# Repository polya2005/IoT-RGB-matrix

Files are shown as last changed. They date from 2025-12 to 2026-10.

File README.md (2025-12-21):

# IoT-RGB-matrix

## Functionalities

- Sending custom images (and animations) over WiFi to the display.
- Automatically generate a QR code for display (one application is to rickroll people)
- Serving as a "status" display like date/time, weather, etc.

## Project Components

- 40x40 RGB LED matrix, which is broken down into 25 PCBs of 8x8 matrix
- A control board, which is likely a Raspberry Pi Zero W

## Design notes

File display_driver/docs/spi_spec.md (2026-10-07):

# SPI Communication Specification for the FPGA-Based Display Driver

## Basic Configurations

- Most Significant Bit (MSB) first.
- Clock phase = 0 and clock polarity = 0. Data is sampled on the rising edge of SCLK and shifted out on the falling edge.
- The data are processed byte by byte, i.e., the driver considers bits 0-7 as a command and bits 8-15, 16-23, ... as data.

## Conventions Used
- Byte 0 is the command. Data start at byte 1.

## Commands
### SPI_CMD_NOP

#### Command Byte:
`8'h00`

#### Data Bytes:
None

#### Description:
When the driver receives this command, it does nothing just like the name suggests.

### SPI_CMD_SET_PIXEL

#### Command Byte:
`8'h01`

#### Data Bytes:

| Byte number | Description|
| --- | --- |
| 1 | Row number (0-39) |
| 2 | Column number (0-39) |
| 3 | Red pixel value (0-255) |
| 4 | Green pixel value (0-255) |
| 5 | Blue pixel value (0-255) |

#### Description:
This command sets the pixel at the specified row and column, both zero-based, to the given set of RGB values.

### SPI_CMD_CLEAR_SCREEN

#### Command Byte:
`8'h02`

#### Data Bytes:
None

#### Description:
This command clears the frame buffer, filling every byte with a zero. As a result, all LEDs should be turned off.

### SPI_CMD_WRITE_BUFFER

### Command Byte:
`8'h03`

#### Data Bytes:

| Byte number | Description |
| --- | --- |
| $3(40r+c)+1$ | Red pixel value (0-255) at row $r$ and column $c$ |
| $3(40r+c)+2$ | Green pixel value (0-255) at row $r$ and column $c$ |
| $3(40r+c)+3$ | Blue pixel value (0-255) at row $r$ and column $c$ |

#### Description:
This command fills the frame buffer with the specified pixel values. The pixel values are given from the top left to the right and down.

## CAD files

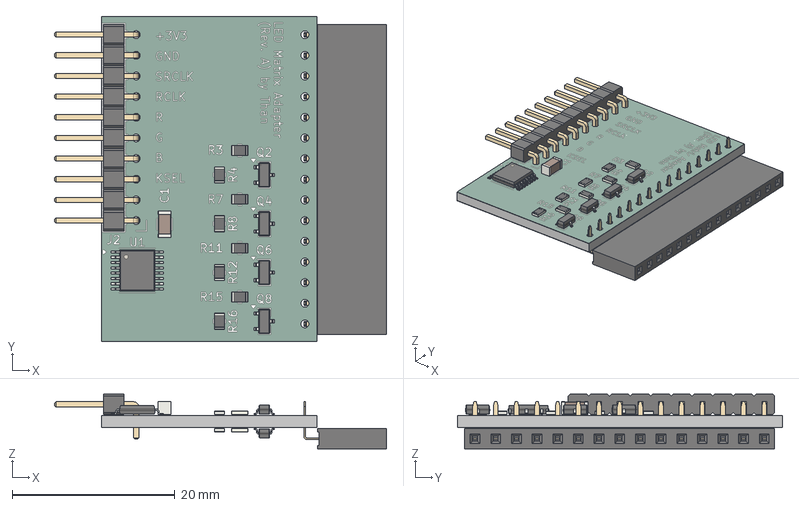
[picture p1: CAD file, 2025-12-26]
pcb/Adapter/Adapter.step
40.8 x 40.0 x 6.76 mm
R_0805_2012Metric x 16
SOT-23 x 8
PinHeader_1x10_P2.54mm_Horizontal
TSSOP-16_4.4x5mm_P0.65mm
C_1206_3216Metric
PinSocket_1x15_P2.54mm_Horizontal
Adapter_silkscreen
Adapter_soldermask
Adapter_PCB

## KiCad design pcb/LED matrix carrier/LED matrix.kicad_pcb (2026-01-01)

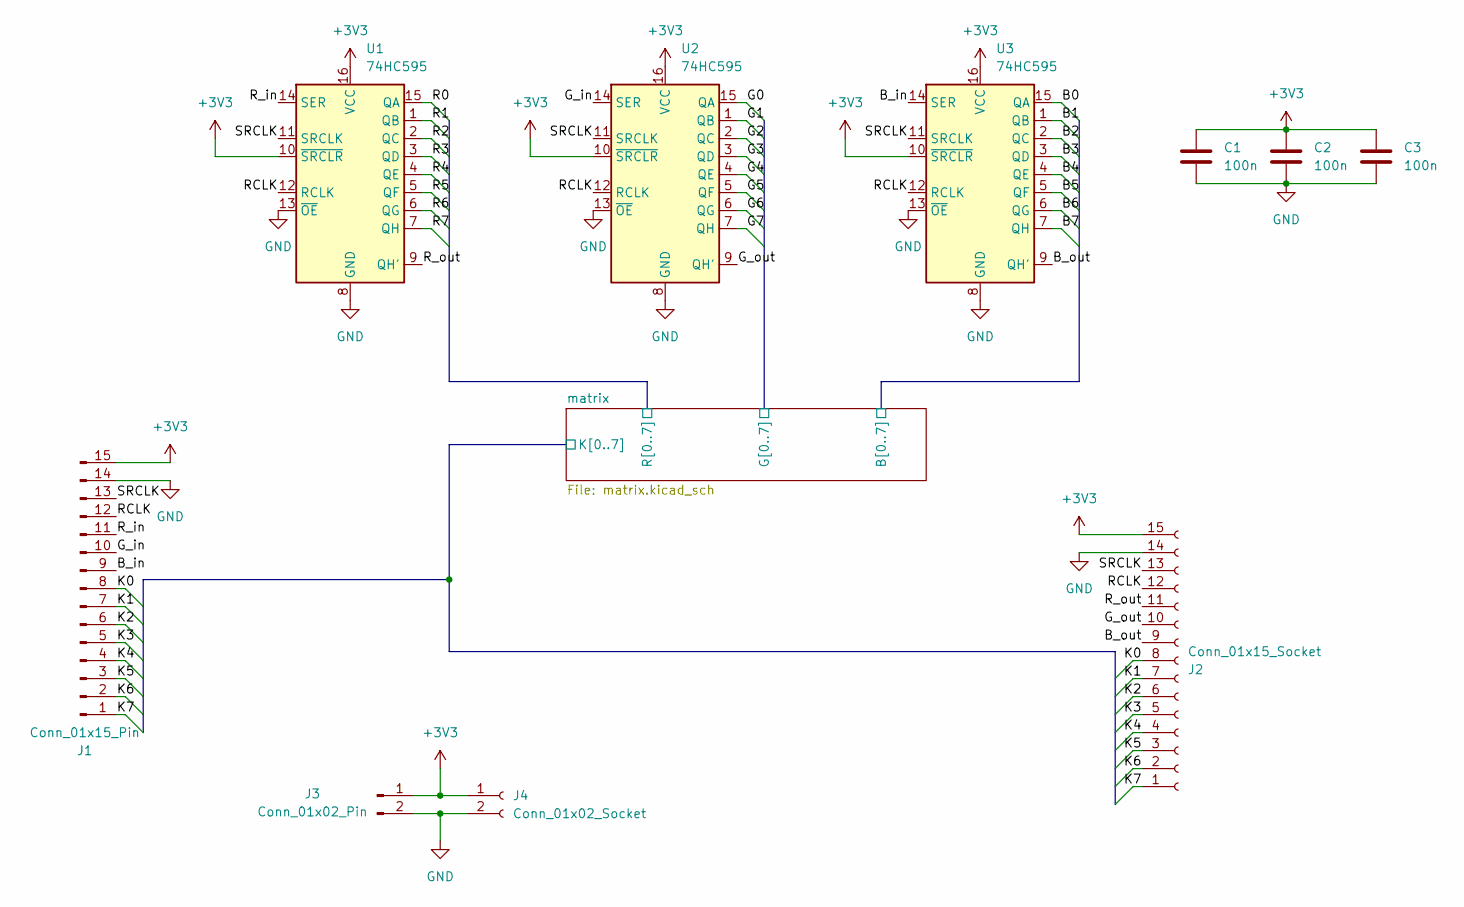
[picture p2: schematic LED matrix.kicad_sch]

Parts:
C1, C2, C3: 100n; C_1206_3216Metric_Pad1.33x1.80mm_HandSolder
J1: Conn_01x15_Pin; PinHeader_1x15_P2.54mm_Horizontal
J2: Conn_01x15_Socket; PinSocket_1x15_P2.54mm_Horizontal
J3: Conn_01x02_Pin; PinHeader_1x02_P2.54mm_Horizontal
J4: Conn_01x02_Socket; PinSocket_1x02_P2.54mm_Horizontal
U1, U2, U3: 74HC595; TSSOP-16_4.4x5mm_P0.65mm

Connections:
+3V3: C1.1, C2.1, C3.1, J1.15, J2.15, J3.1, J4.1, U1.10 (~SRCLR), U1.16 (VCC), U2.10 (~SRCLR), U2.16 (VCC), U3.10 (~SRCLR), U3.16 (VCC)
/B_in: J1.9, U3.14 (SER)
/B_out: J2.9, U3.9 (QH')
/G_in: J1.10, U2.14 (SER)
/G_out: J2.10, U2.9 (QH')
/RCLK: J1.12, J2.12, U1.12 (RCLK), U2.12 (RCLK), U3.12 (RCLK)
/R_in: J1.11, U1.14 (SER)
/R_out: J2.11, U1.9 (QH')
/SRCLK: J1.13, J2.13, U1.11 (SRCLK), U2.11 (SRCLK), U3.11 (SRCLK)
/matrix/B0: U3.15 (QA); also elsewhere on the board
/matrix/B1: U3.1 (QB); also elsewhere on the board
/matrix/B2: U3.2 (QC); also elsewhere on the board
/matrix/B3: U3.3 (QD); also elsewhere on the board
/matrix/B4: U3.4 (QE); also elsewhere on the board
/matrix/B5: U3.5 (QF); also elsewhere on the board
/matrix/B6: U3.6 (QG); also elsewhere on the board
/matrix/B7: U3.7 (QH); also elsewhere on the board
/matrix/G0: U2.15 (QA); also elsewhere on the board
/matrix/G1: U2.1 (QB); also elsewhere on the board
/matrix/G2: U2.2 (QC); also elsewhere on the board
/matrix/G3: U2.3 (QD); also elsewhere on the board
/matrix/G4: U2.4 (QE); also elsewhere on the board
/matrix/G5: U2.5 (QF); also elsewhere on the board
/matrix/G6: U2.6 (QG); also elsewhere on the board
/matrix/G7: U2.7 (QH); also elsewhere on the board
/matrix/K0: J1.8, J2.8; also elsewhere on the board
/matrix/K1: J1.7, J2.7; also elsewhere on the board
/matrix/K2: J1.6, J2.6; also elsewhere on the board
/matrix/K3: J1.5, J2.5; also elsewhere on the board
/matrix/K4: J1.4, J2.4; also elsewhere on the board
/matrix/K5: J1.3, J2.3; also elsewhere on the board
/matrix/K6: J1.2, J2.2; also elsewhere on the board
/matrix/K7: J1.1, J2.1; also elsewhere on the board
/matrix/R0: U1.15 (QA); also elsewhere on the board
/matrix/R1: U1.1 (QB); also elsewhere on the board
/matrix/R2: U1.2 (QC); also elsewhere on the board
/matrix/R3: U1.3 (QD); also elsewhere on the board
/matrix/R4: U1.4 (QE); also elsewhere on the board
/matrix/R5: U1.5 (QF); also elsewhere on the board
/matrix/R6: U1.6 (QG); also elsewhere on the board
/matrix/R7: U1.7 (QH); also elsewhere on the board
GND: C1.2, C2.2, C3.2, J1.14, J2.14, J3.2, J4.2, U1.8 (GND), U1.13 (~OE), U2.8 (GND), U2.13 (~OE), U3.8 (GND), U3.13 (~OE)

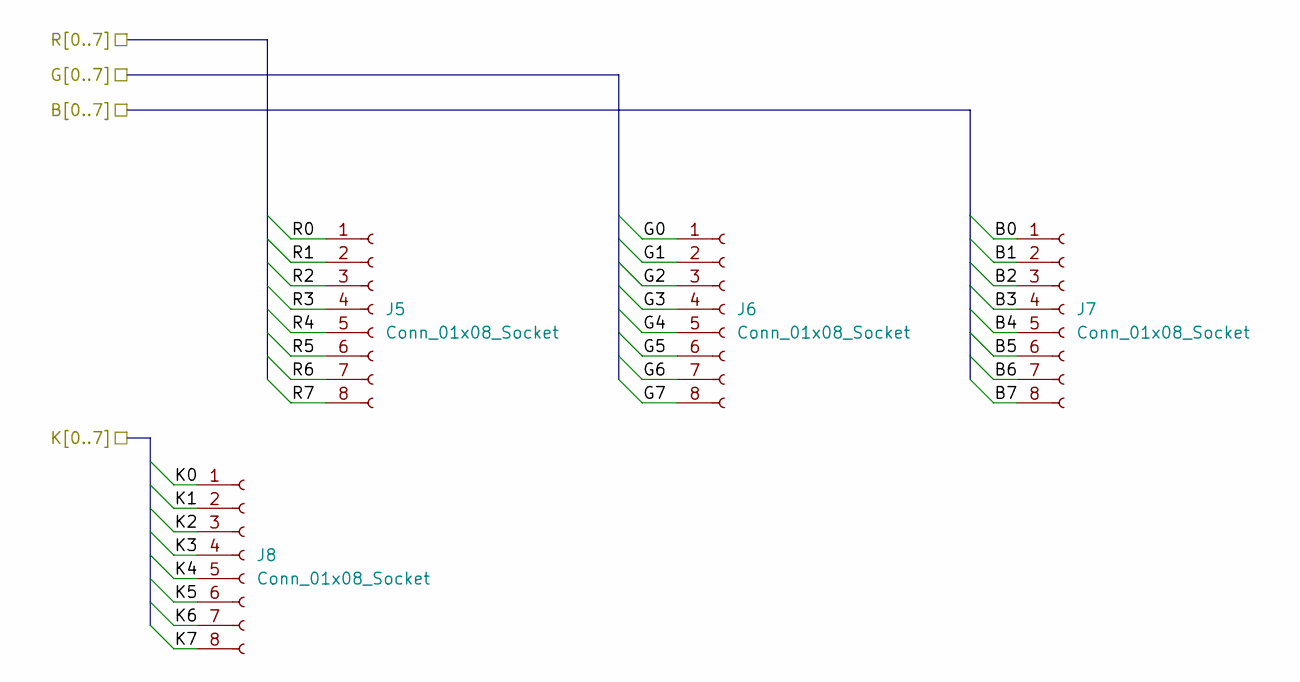
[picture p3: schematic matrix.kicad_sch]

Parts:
J5, J6, J7, J8: Conn_01x08_Socket; PinSocket_1x08_P2.54mm_Vertical

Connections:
/matrix/B0: J7.1; also elsewhere on the board
/matrix/B1: J7.2; also elsewhere on the board
/matrix/B2: J7.3; also elsewhere on the board
/matrix/B3: J7.4; also elsewhere on the board
/matrix/B4: J7.5; also elsewhere on the board
/matrix/B5: J7.6; also elsewhere on the board
/matrix/B6: J7.7; also elsewhere on the board
/matrix/B7: J7.8; also elsewhere on the board
/matrix/G0: J6.1; also elsewhere on the board
/matrix/G1: J6.2; also elsewhere on the board
/matrix/G2: J6.3; also elsewhere on the board
/matrix/G3: J6.4; also elsewhere on the board
/matrix/G4: J6.5; also elsewhere on the board
/matrix/G5: J6.6; also elsewhere on the board
/matrix/G6: J6.7; also elsewhere on the board
/matrix/G7: J6.8; also elsewhere on the board
/matrix/K0: J8.1; also elsewhere on the board
/matrix/K1: J8.2; also elsewhere on the board
/matrix/K2: J8.3; also elsewhere on the board
/matrix/K3: J8.4; also elsewhere on the board
/matrix/K4: J8.5; also elsewhere on the board
/matrix/K5: J8.6; also elsewhere on the board
/matrix/K6: J8.7; also elsewhere on the board
/matrix/K7: J8.8; also elsewhere on the board
/matrix/R0: J5.1; also elsewhere on the board
/matrix/R1: J5.2; also elsewhere on the board
/matrix/R2: J5.3; also elsewhere on the board
/matrix/R3: J5.4; also elsewhere on the board
/matrix/R4: J5.5; also elsewhere on the board
/matrix/R5: J5.6; also elsewhere on the board
/matrix/R6: J5.7; also elsewhere on the board
/matrix/R7: J5.8; also elsewhere on the board

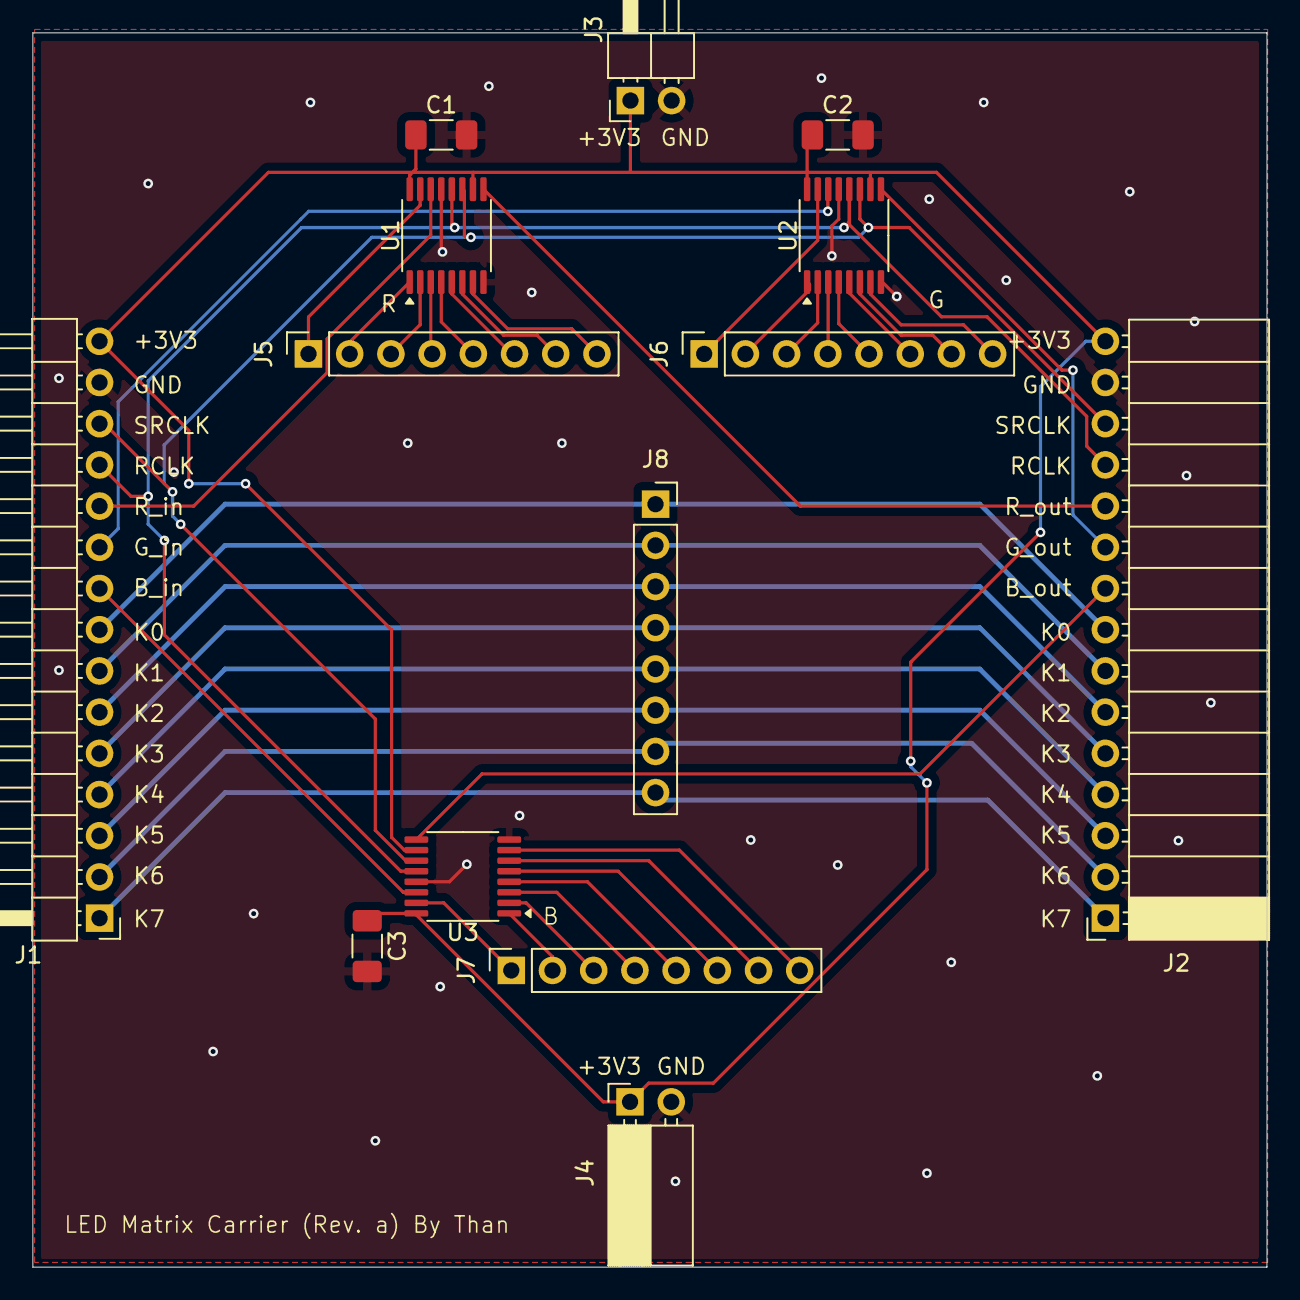
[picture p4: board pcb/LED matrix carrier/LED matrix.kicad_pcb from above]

Board: 2 copper layers, 76.1 x 76.1 mm, 14 parts (0 on the bottom side), 42 nets.

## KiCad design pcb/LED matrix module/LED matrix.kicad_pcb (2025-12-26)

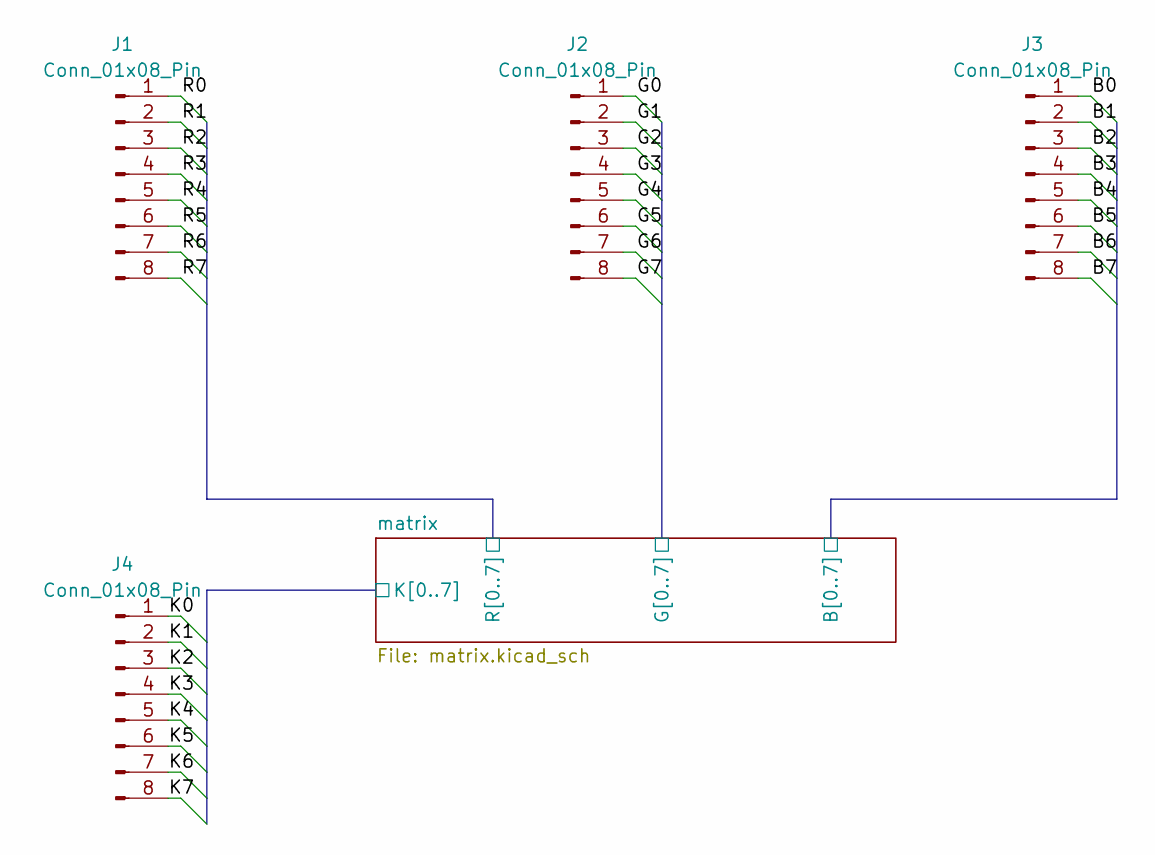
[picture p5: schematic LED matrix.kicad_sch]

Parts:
J1, J2, J3, J4: Conn_01x08_Pin; PinHeader_1x08_P2.54mm_Vertical

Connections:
/matrix/B0: J3.1; also elsewhere on the board
/matrix/B1: J3.2; also elsewhere on the board
/matrix/B2: J3.3; also elsewhere on the board
/matrix/B3: J3.4; also elsewhere on the board
/matrix/B4: J3.5; also elsewhere on the board
/matrix/B5: J3.6; also elsewhere on the board
/matrix/B6: J3.7; also elsewhere on the board
/matrix/B7: J3.8; also elsewhere on the board
/matrix/G0: J2.1; also elsewhere on the board
/matrix/G1: J2.2; also elsewhere on the board
/matrix/G2: J2.3; also elsewhere on the board
/matrix/G3: J2.4; also elsewhere on the board
/matrix/G4: J2.5; also elsewhere on the board
/matrix/G5: J2.6; also elsewhere on the board
/matrix/G6: J2.7; also elsewhere on the board
/matrix/G7: J2.8; also elsewhere on the board
/matrix/K0: J4.1; also elsewhere on the board
/matrix/K1: J4.2; also elsewhere on the board
/matrix/K2: J4.3; also elsewhere on the board
/matrix/K3: J4.4; also elsewhere on the board
/matrix/K4: J4.5; also elsewhere on the board
/matrix/K5: J4.6; also elsewhere on the board
/matrix/K6: J4.7; also elsewhere on the board
/matrix/K7: J4.8; also elsewhere on the board
/matrix/R0: J1.1; also elsewhere on the board
/matrix/R1: J1.2; also elsewhere on the board
/matrix/R2: J1.3; also elsewhere on the board
/matrix/R3: J1.4; also elsewhere on the board
/matrix/R4: J1.5; also elsewhere on the board
/matrix/R5: J1.6; also elsewhere on the board
/matrix/R6: J1.7; also elsewhere on the board
/matrix/R7: J1.8; also elsewhere on the board

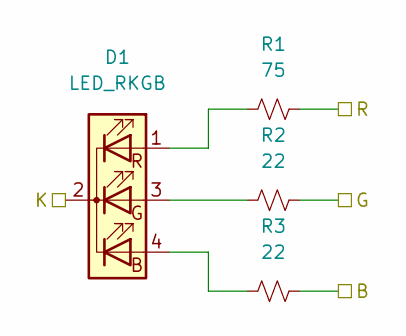
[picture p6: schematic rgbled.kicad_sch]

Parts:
D1: LED_RKGB; LED_D5.0mm-4_RGB
R1: 75; R_0402_1005Metric; LCSC C25133
R2, R3: 22; R_0402_1005Metric; LCSC C25092

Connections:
/matrix/B0: R3.2; also elsewhere on the board
/matrix/G0: R2.2; also elsewhere on the board
/matrix/K0: D1.2 (K); also elsewhere on the board
/matrix/R0: R1.2; also elsewhere on the board
unnamed: D1.4 (BA), R3.1
unnamed: D1.3 (GA), R2.1
unnamed: D1.1 (RA), R1.1

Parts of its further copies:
D2, D3, D4, D5, D6, D7, D8, D9, D10, D11, D12, D13, D14, D15, D16, D17, D18, D19, D20, D21, D22, D23, D24, D25, D26, D27, D28, D29, D30, D31, D32, D33, D34, D35, D36, D37, D38, D39, D40, D41, D42, D43, D44, D45, D46, D47, D48, D49, D50, D51, D52, D53, D54, D55, D56, D57, D58, D59, D60, D61, D62, D63, D64: LED_RKGB; LED_D5.0mm-4_RGB
R4, R7, R10, R13, R16, R19, R22, R25, R28, R31, R34, R37, R40, R43, R46, R49, R52, R55, R58, R61, R64, R67, R70, R73, R76, R79, R82, R85, R88, R91, R94, R97, R100, R103, R106, R109, R112, R115, R118, R121, R124, R127, R130, R133, R136, R139, R142, R145, R148, R151, R154, R157, R160, R163, R166, R169, R172, R175, R178, R181, R184, R187, R190: 75; R_0402_1005Metric; LCSC C25133
R5, R6, R8, R9, R11, R12, R14, R15, R17, R18, R20, R21, R23, R24, R26, R27, R29, R30, R32, R33, R35, R36, R38, R39, R41, R42, R44, R45, R47, R48, R50, R51, R53, R54, R56, R57, R59, R60, R62, R63, R65, R66, R68, R69, R71, R72, R74, R75, R77, R78, R80, R81, R83, R84, R86, R87, R89, R90, R92, R93, R95, R96, R98, R99, R101, R102, R104, R105, R107, R108, R110, R111, R113, R114, R116, R117, R119, R120, R122, R123, R125, R126, R128, R129, R131, R132, R134, R135, R137, R138, R140, R141, R143, R144, R146, R147, R149, R150, R152, R153, R155, R156, R158, R159, R161, R162, R164, R165, R167, R168, R170, R171, R173, R174, R176, R177, R179, R180, R182, R183, R185, R186, R188, R189, R191, R192: 22; R_0402_1005Metric; LCSC C25092

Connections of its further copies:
/matrix/B0: R6.2, R9.2, R12.2, R15.2, R18.2, R21.2, R24.2; also elsewhere on the board
/matrix/B1: R27.2, R30.2, R33.2, R36.2, R39.2, R42.2, R45.2, R48.2; also elsewhere on the board
/matrix/B2: R51.2, R54.2, R57.2, R60.2, R63.2, R66.2, R69.2, R72.2; also elsewhere on the board
/matrix/B3: R75.2, R78.2, R81.2, R84.2, R87.2, R90.2, R93.2, R96.2; also elsewhere on the board
/matrix/B4: R99.2, R102.2, R105.2, R108.2, R111.2, R114.2, R117.2, R120.2; also elsewhere on the board
/matrix/B5: R123.2, R126.2, R129.2, R132.2, R135.2, R138.2, R141.2, R144.2; also elsewhere on the board
/matrix/B6: R147.2, R150.2, R153.2, R156.2, R159.2, R162.2, R165.2, R168.2; also elsewhere on the board
/matrix/B7: R171.2, R174.2, R177.2, R180.2, R183.2, R186.2, R189.2, R192.2; also elsewhere on the board
/matrix/G0: R5.2, R8.2, R11.2, R14.2, R17.2, R20.2, R23.2; also elsewhere on the board
/matrix/G1: R26.2, R29.2, R32.2, R35.2, R38.2, R41.2, R44.2, R47.2; also elsewhere on the board
/matrix/G2: R50.2, R53.2, R56.2, R59.2, R62.2, R65.2, R68.2, R71.2; also elsewhere on the board
/matrix/G3: R74.2, R77.2, R80.2, R83.2, R86.2, R89.2, R92.2, R95.2; also elsewhere on the board
/matrix/G4: R98.2, R101.2, R104.2, R107.2, R110.2, R113.2, R116.2, R119.2; also elsewhere on the board
/matrix/G5: R122.2, R125.2, R128.2, R131.2, R134.2, R137.2, R140.2, R143.2; also elsewhere on the board
/matrix/G6: R146.2, R149.2, R152.2, R155.2, R158.2, R161.2, R164.2, R167.2; also elsewhere on the board
/matrix/G7: R170.2, R173.2, R176.2, R179.2, R182.2, R185.2, R188.2, R191.2; also elsewhere on the board
/matrix/K0: D9.2 (K), D17.2 (K), D25.2 (K), D33.2 (K), D41.2 (K), D49.2 (K), D57.2 (K); also elsewhere on the board
/matrix/K1: D2.2 (K), D10.2 (K), D18.2 (K), D26.2 (K), D34.2 (K), D42.2 (K), D50.2 (K), D58.2 (K); also elsewhere on the board
/matrix/K2: D3.2 (K), D11.2 (K), D19.2 (K), D27.2 (K), D35.2 (K), D43.2 (K), D51.2 (K), D59.2 (K); also elsewhere on the board
/matrix/K3: D4.2 (K), D12.2 (K), D20.2 (K), D28.2 (K), D36.2 (K), D44.2 (K), D52.2 (K), D60.2 (K); also elsewhere on the board
/matrix/K4: D5.2 (K), D13.2 (K), D21.2 (K), D29.2 (K), D37.2 (K), D45.2 (K), D53.2 (K), D61.2 (K); also elsewhere on the board
/matrix/K5: D6.2 (K), D14.2 (K), D22.2 (K), D30.2 (K), D38.2 (K), D46.2 (K), D54.2 (K), D62.2 (K); also elsewhere on the board
/matrix/K6: D7.2 (K), D15.2 (K), D23.2 (K), D31.2 (K), D39.2 (K), D47.2 (K), D55.2 (K), D63.2 (K); also elsewhere on the board
/matrix/K7: D8.2 (K), D16.2 (K), D24.2 (K), D32.2 (K), D40.2 (K), D48.2 (K), D56.2 (K), D64.2 (K); also elsewhere on the board
/matrix/R0: R4.2, R7.2, R10.2, R13.2, R16.2, R19.2, R22.2; also elsewhere on the board
/matrix/R1: R25.2, R28.2, R31.2, R34.2, R37.2, R40.2, R43.2, R46.2; also elsewhere on the board
/matrix/R2: R49.2, R52.2, R55.2, R58.2, R61.2, R64.2, R67.2, R70.2; also elsewhere on the board
/matrix/R3: R73.2, R76.2, R79.2, R82.2, R85.2, R88.2, R91.2, R94.2; also elsewhere on the board
/matrix/R4: R97.2, R100.2, R103.2, R106.2, R109.2, R112.2, R115.2, R118.2; also elsewhere on the board
/matrix/R5: R121.2, R124.2, R127.2, R130.2, R133.2, R136.2, R139.2, R142.2; also elsewhere on the board
/matrix/R6: R145.2, R148.2, R151.2, R154.2, R157.2, R160.2, R163.2, R166.2; also elsewhere on the board
/matrix/R7: R169.2, R172.2, R175.2, R178.2, R181.2, R184.2, R187.2, R190.2; also elsewhere on the board
unnamed: D2.4 (BA), R6.1
unnamed: D2.3 (GA), R5.1
unnamed: D2.1 (RA), R4.1
unnamed: D3.4 (BA), R9.1
unnamed: D3.3 (GA), R8.1
unnamed: D3.1 (RA), R7.1
unnamed: D4.4 (BA), R12.1
unnamed: D4.3 (GA), R11.1
unnamed: D4.1 (RA), R10.1
unnamed: D5.4 (BA), R15.1
unnamed: D5.3 (GA), R14.1
unnamed: D5.1 (RA), R13.1
unnamed: D6.4 (BA), R18.1
unnamed: D6.3 (GA), R17.1
unnamed: D6.1 (RA), R16.1
unnamed: D7.4 (BA), R21.1
unnamed: D7.3 (GA), R20.1
unnamed: D7.1 (RA), R19.1
unnamed: D8.4 (BA), R24.1
unnamed: D8.3 (GA), R23.1
unnamed: D8.1 (RA), R22.1
unnamed: D9.4 (BA), R27.1
unnamed: D9.3 (GA), R26.1
unnamed: D9.1 (RA), R25.1
unnamed: D10.4 (BA), R30.1
unnamed: D10.3 (GA), R29.1
unnamed: D10.1 (RA), R28.1
unnamed: D11.4 (BA), R33.1
unnamed: D11.3 (GA), R32.1
unnamed: D11.1 (RA), R31.1
unnamed: D12.4 (BA), R36.1
unnamed: D12.3 (GA), R35.1
unnamed: D12.1 (RA), R34.1
unnamed: D13.4 (BA), R39.1
unnamed: D13.3 (GA), R38.1
unnamed: D13.1 (RA), R37.1
unnamed: D14.4 (BA), R42.1
unnamed: D14.3 (GA), R41.1
unnamed: D14.1 (RA), R40.1
unnamed: D15.4 (BA), R45.1
unnamed: D15.3 (GA), R44.1
unnamed: D15.1 (RA), R43.1
unnamed: D16.4 (BA), R48.1
unnamed: D16.3 (GA), R47.1
unnamed: D16.1 (RA), R46.1
unnamed: D17.4 (BA), R51.1
unnamed: D17.3 (GA), R50.1
unnamed: D17.1 (RA), R49.1
unnamed: D18.4 (BA), R54.1
unnamed: D18.3 (GA), R53.1
unnamed: D18.1 (RA), R52.1
unnamed: D19.4 (BA), R57.1
unnamed: D19.3 (GA), R56.1
unnamed: D19.1 (RA), R55.1
unnamed: D20.4 (BA), R60.1
unnamed: D20.3 (GA), R59.1
unnamed: D20.1 (RA), R58.1
unnamed: D21.4 (BA), R63.1
unnamed: D21.3 (GA), R62.1
unnamed: D21.1 (RA), R61.1
unnamed: D22.4 (BA), R66.1
unnamed: D22.3 (GA), R65.1
unnamed: D22.1 (RA), R64.1
unnamed: D23.4 (BA), R69.1
unnamed: D23.3 (GA), R68.1
unnamed: D23.1 (RA), R67.1
unnamed: D24.4 (BA), R72.1
unnamed: D24.3 (GA), R71.1
unnamed: D24.1 (RA), R70.1
unnamed: D25.4 (BA), R75.1
unnamed: D25.3 (GA), R74.1
unnamed: D25.1 (RA), R73.1
unnamed: D26.4 (BA), R78.1
unnamed: D26.3 (GA), R77.1
unnamed: D26.1 (RA), R76.1
unnamed: D27.4 (BA), R81.1
unnamed: D27.3 (GA), R80.1
unnamed: D27.1 (RA), R79.1
unnamed: D28.4 (BA), R84.1
unnamed: D28.3 (GA), R83.1
unnamed: D28.1 (RA), R82.1
unnamed: D29.4 (BA), R87.1
unnamed: D29.3 (GA), R86.1
unnamed: D29.1 (RA), R85.1
unnamed: D30.4 (BA), R90.1
unnamed: D30.3 (GA), R89.1
unnamed: D30.1 (RA), R88.1
unnamed: D31.4 (BA), R93.1
unnamed: D31.3 (GA), R92.1
unnamed: D31.1 (RA), R91.1
unnamed: D32.4 (BA), R96.1
unnamed: D32.3 (GA), R95.1
unnamed: D32.1 (RA), R94.1
unnamed: D33.4 (BA), R99.1
unnamed: D33.3 (GA), R98.1
unnamed: D33.1 (RA), R97.1
unnamed: D34.4 (BA), R102.1
unnamed: D34.3 (GA), R101.1
unnamed: D34.1 (RA), R100.1
unnamed: D35.4 (BA), R105.1
unnamed: D35.3 (GA), R104.1
unnamed: D35.1 (RA), R103.1
unnamed: D36.4 (BA), R108.1
unnamed: D36.3 (GA), R107.1
unnamed: D36.1 (RA), R106.1
unnamed: D37.4 (BA), R111.1
unnamed: D37.3 (GA), R110.1
unnamed: D37.1 (RA), R109.1
unnamed: D38.4 (BA), R114.1
unnamed: D38.3 (GA), R113.1
unnamed: D38.1 (RA), R112.1
unnamed: D39.4 (BA), R117.1
unnamed: D39.3 (GA), R116.1
unnamed: D39.1 (RA), R115.1
unnamed: D40.4 (BA), R120.1
unnamed: D40.3 (GA), R119.1
unnamed: D40.1 (RA), R118.1
unnamed: D41.4 (BA), R123.1
unnamed: D41.3 (GA), R122.1
unnamed: D41.1 (RA), R121.1
unnamed: D42.4 (BA), R126.1
unnamed: D42.3 (GA), R125.1
unnamed: D42.1 (RA), R124.1
unnamed: D43.4 (BA), R129.1
unnamed: D43.3 (GA), R128.1
unnamed: D43.1 (RA), R127.1
unnamed: D44.4 (BA), R132.1
unnamed: D44.3 (GA), R131.1
unnamed: D44.1 (RA), R130.1
unnamed: D45.4 (BA), R135.1
unnamed: D45.3 (GA), R134.1
unnamed: D45.1 (RA), R133.1
unnamed: D46.4 (BA), R138.1
unnamed: D46.3 (GA), R137.1
unnamed: D46.1 (RA), R136.1
unnamed: D47.4 (BA), R141.1
unnamed: D47.3 (GA), R140.1
unnamed: D47.1 (RA), R139.1
unnamed: D48.4 (BA), R144.1
unnamed: D48.3 (GA), R143.1
unnamed: D48.1 (RA), R142.1
unnamed: D49.4 (BA), R147.1
unnamed: D49.3 (GA), R146.1
unnamed: D49.1 (RA), R145.1
unnamed: D50.4 (BA), R150.1
unnamed: D50.3 (GA), R149.1
unnamed: D50.1 (RA), R148.1
unnamed: D51.4 (BA), R153.1
unnamed: D51.3 (GA), R152.1
unnamed: D51.1 (RA), R151.1
unnamed: D52.4 (BA), R156.1
unnamed: D52.3 (GA), R155.1
unnamed: D52.1 (RA), R154.1
unnamed: D53.4 (BA), R159.1
unnamed: D53.3 (GA), R158.1
unnamed: D53.1 (RA), R157.1
unnamed: D54.4 (BA), R162.1
unnamed: D54.3 (GA), R161.1
unnamed: D54.1 (RA), R160.1
unnamed: D55.4 (BA), R165.1
unnamed: D55.3 (GA), R164.1
unnamed: D55.1 (RA), R163.1
unnamed: D56.4 (BA), R168.1
unnamed: D56.3 (GA), R167.1
unnamed: D56.1 (RA), R166.1
unnamed: D57.4 (BA), R171.1
unnamed: D57.3 (GA), R170.1
unnamed: D57.1 (RA), R169.1
unnamed: D58.4 (BA), R174.1
unnamed: D58.3 (GA), R173.1
unnamed: D58.1 (RA), R172.1
unnamed: D59.4 (BA), R177.1
unnamed: D59.3 (GA), R176.1
unnamed: D59.1 (RA), R175.1
unnamed: D60.4 (BA), R180.1
unnamed: D60.3 (GA), R179.1
unnamed: D60.1 (RA), R178.1
unnamed: D61.4 (BA), R183.1
unnamed: D61.3 (GA), R182.1
unnamed: D61.1 (RA), R181.1
unnamed: D62.4 (BA), R186.1
unnamed: D62.3 (GA), R185.1
unnamed: D62.1 (RA), R184.1
unnamed: D63.4 (BA), R189.1
unnamed: D63.3 (GA), R188.1
unnamed: D63.1 (RA), R187.1
unnamed: D64.4 (BA), R192.1
unnamed: D64.3 (GA), R191.1
unnamed: D64.1 (RA), R190.1

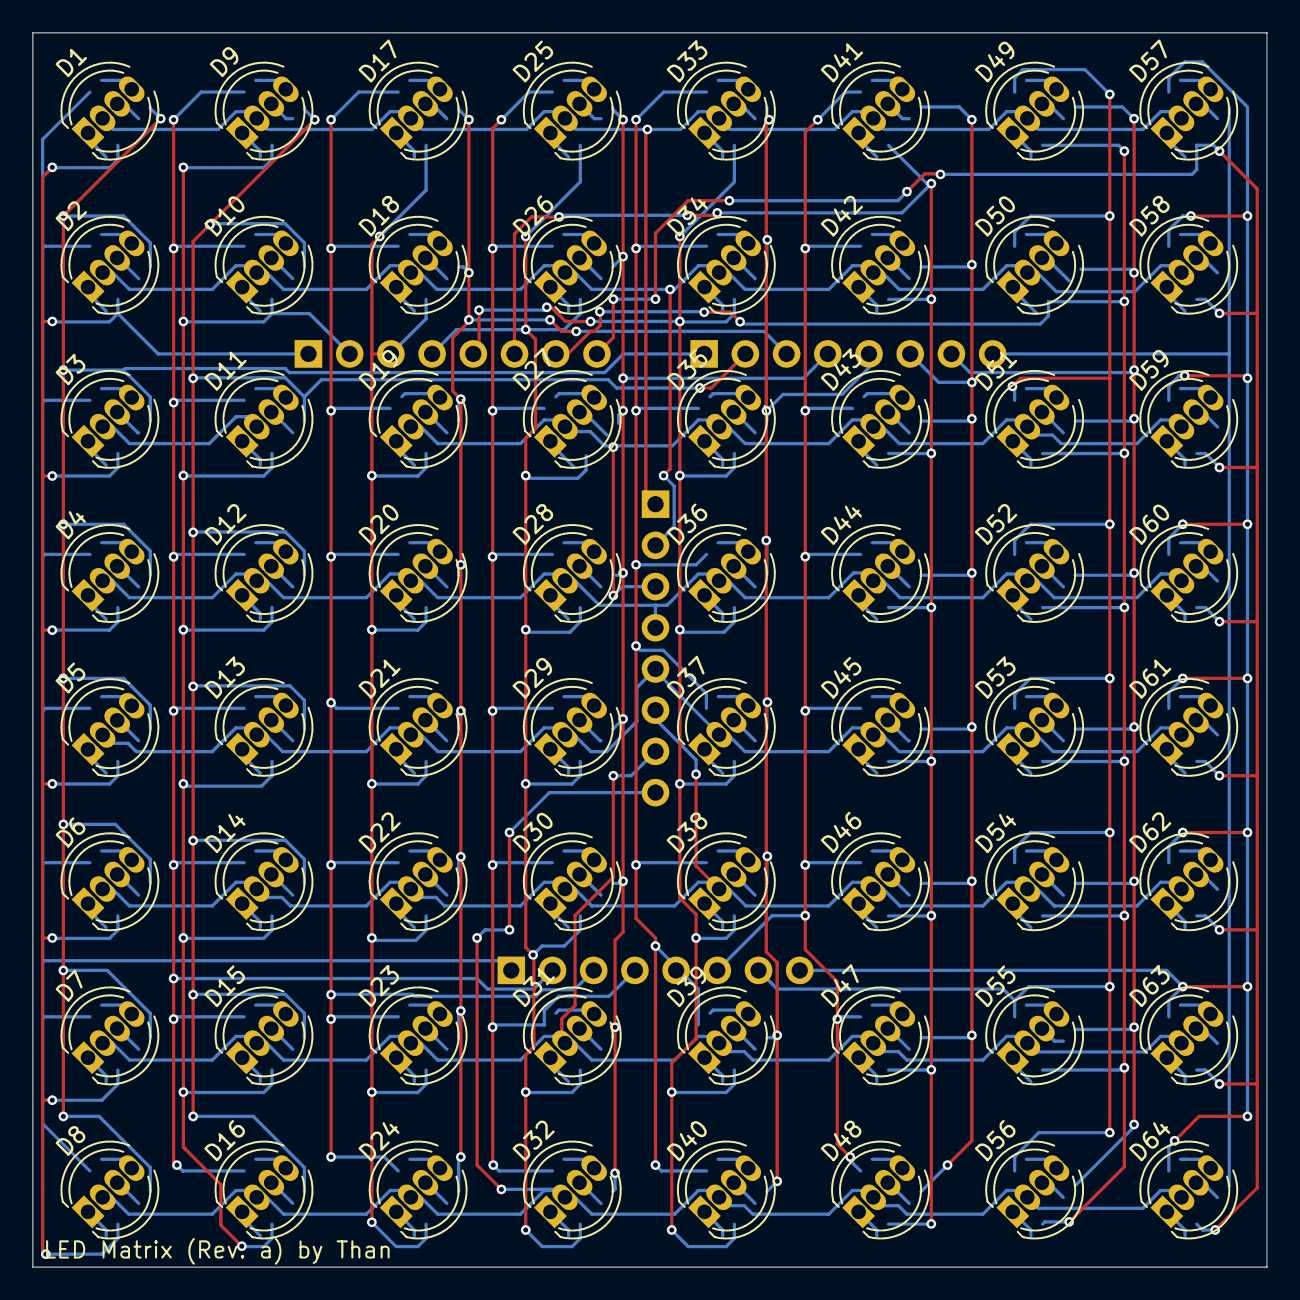
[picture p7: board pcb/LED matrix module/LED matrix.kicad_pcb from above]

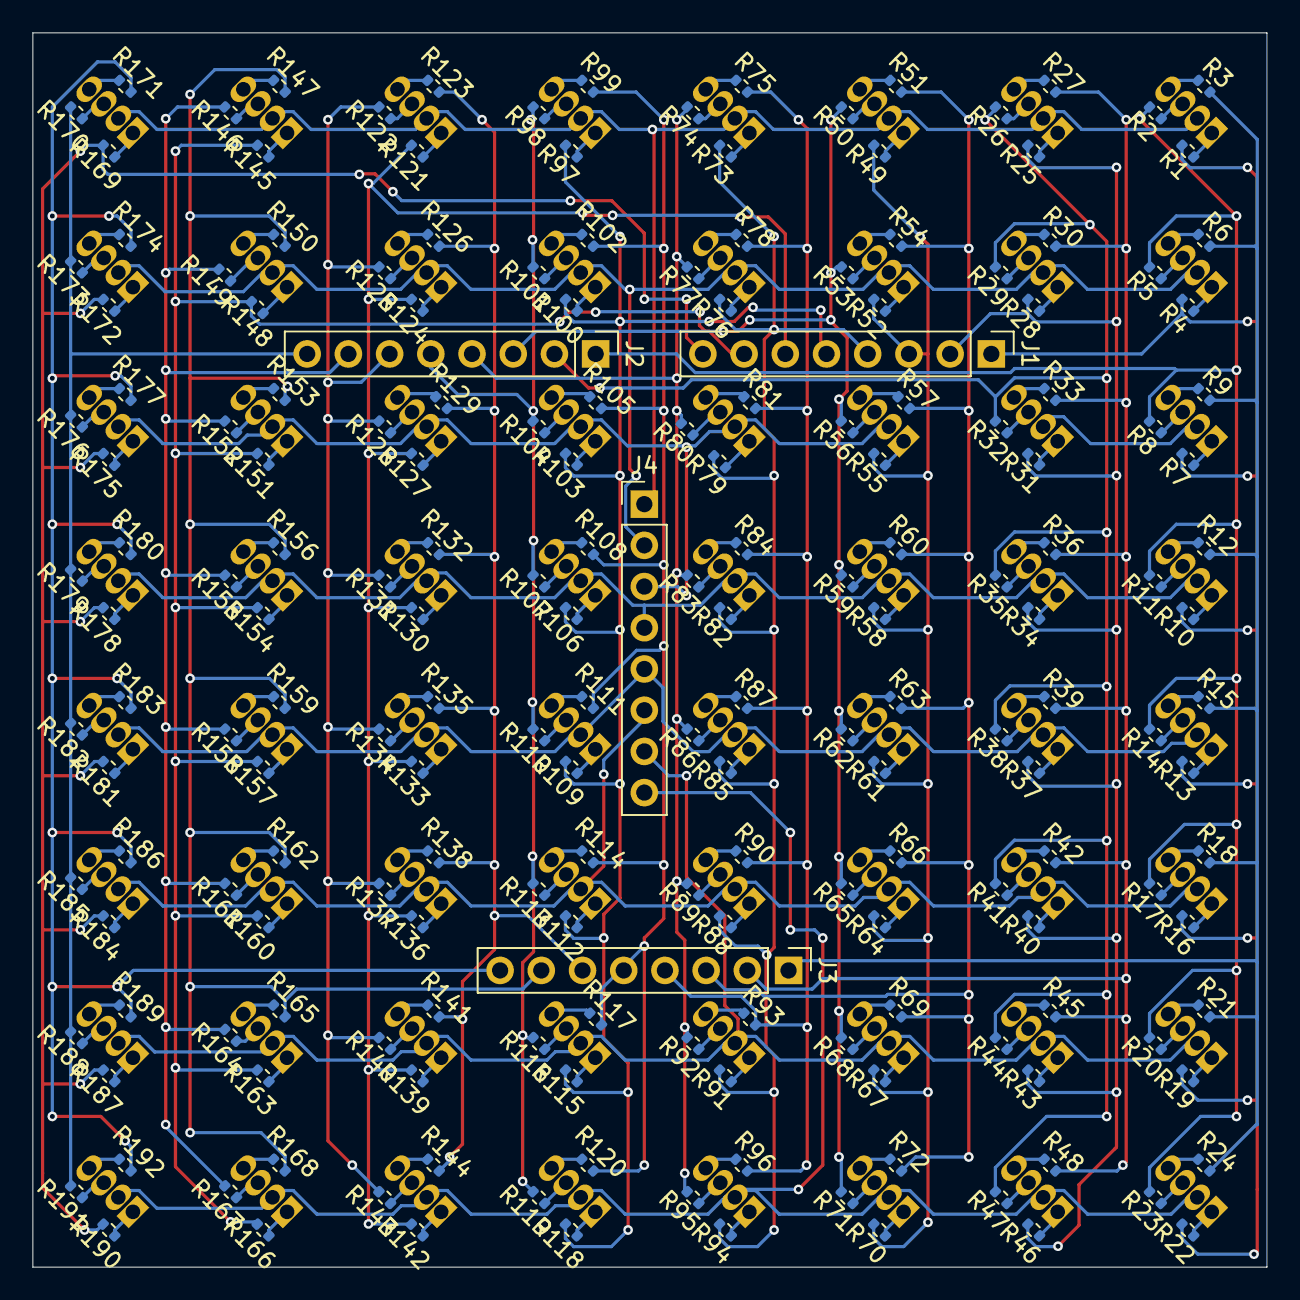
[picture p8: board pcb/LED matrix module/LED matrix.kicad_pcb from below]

Board: 2 copper layers, 76.1 x 76.1 mm, 260 parts (196 on the bottom side), 224 nets.

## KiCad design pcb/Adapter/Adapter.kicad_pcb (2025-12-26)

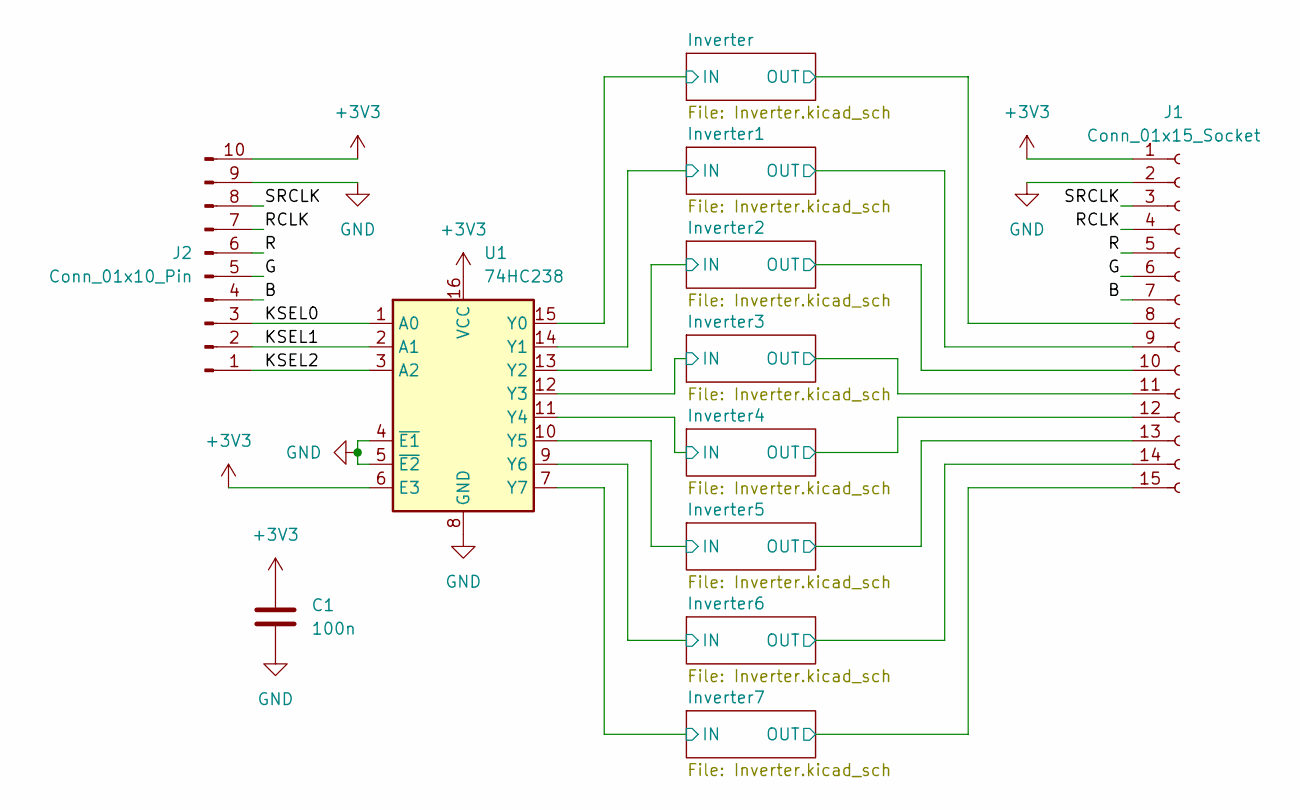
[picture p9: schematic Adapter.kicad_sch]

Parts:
C1: 100n; C_1206_3216Metric_Pad1.33x1.80mm_HandSolder
J1: Conn_01x15_Socket; PinSocket_1x15_P2.54mm_Horizontal
J2: Conn_01x10_Pin; PinHeader_1x10_P2.54mm_Horizontal
U1: 74HC238; TSSOP-16_4.4x5mm_P0.65mm

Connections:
+3V3: C1.1, J1.1, J2.10, U1.6 (E3), U1.16 (VCC)
/B: J1.7, J2.4
/G: J1.6, J2.5
/Inverter1/IN: U1.14 (Y1); also elsewhere on the board
/Inverter1/OUT: J1.9; also elsewhere on the board
/Inverter2/IN: U1.13 (Y2); also elsewhere on the board
/Inverter2/OUT: J1.10; also elsewhere on the board
/Inverter3/IN: U1.12 (Y3); also elsewhere on the board
/Inverter3/OUT: J1.11; also elsewhere on the board
/Inverter4/IN: U1.11 (Y4); also elsewhere on the board
/Inverter4/OUT: J1.12; also elsewhere on the board
/Inverter5/IN: U1.10 (Y5); also elsewhere on the board
/Inverter5/OUT: J1.13; also elsewhere on the board
/Inverter6/IN: U1.9 (Y6); also elsewhere on the board
/Inverter6/OUT: J1.14; also elsewhere on the board
/Inverter7/IN: U1.7 (Y7); also elsewhere on the board
/Inverter7/OUT: J1.15; also elsewhere on the board
/Inverter/IN: U1.15 (Y0); also elsewhere on the board
/Inverter/OUT: J1.8; also elsewhere on the board
/KSEL0: J2.3, U1.1 (A0)
/KSEL1: J2.2, U1.2 (A1)
/KSEL2: J2.1, U1.3 (A2)
/R: J1.5, J2.6
/RCLK: J1.4, J2.7
/SRCLK: J1.3, J2.8
GND: C1.2, J1.2, J2.9, U1.4 (~E1), U1.5 (~E2), U1.8 (GND); also elsewhere on the board

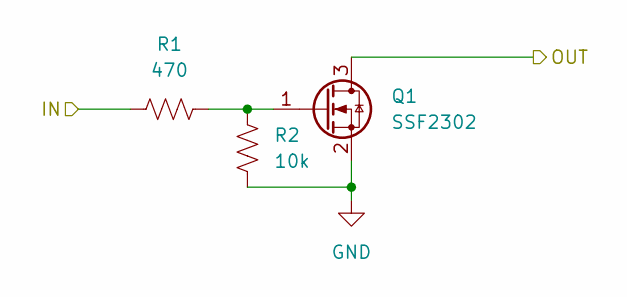
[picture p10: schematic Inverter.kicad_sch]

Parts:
Q1: SSF2302; SOT-23_Handsoldering
R1: 470; R_0805_2012Metric_Pad1.20x1.40mm_HandSolder
R2: 10k; R_0805_2012Metric_Pad1.20x1.40mm_HandSolder

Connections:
/Inverter/IN: R1.1; also elsewhere on the board
/Inverter/OUT: Q1.3 (D); also elsewhere on the board
GND: Q1.2 (S), R2.2; also elsewhere on the board
unnamed: Q1.1 (G), R1.2, R2.1

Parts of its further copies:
Q2, Q3, Q4, Q5, Q6, Q7, Q8: SSF2302; SOT-23_Handsoldering
R3, R5, R7, R9, R11, R13, R15: 470; R_0805_2012Metric_Pad1.20x1.40mm_HandSolder
R4, R6, R8, R10, R12, R14, R16: 10k; R_0805_2012Metric_Pad1.20x1.40mm_HandSolder

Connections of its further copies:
/Inverter1/IN: R3.1; also elsewhere on the board
/Inverter1/OUT: Q2.3 (D); also elsewhere on the board
/Inverter2/IN: R5.1; also elsewhere on the board
/Inverter2/OUT: Q3.3 (D); also elsewhere on the board
/Inverter3/IN: R7.1; also elsewhere on the board
/Inverter3/OUT: Q4.3 (D); also elsewhere on the board
/Inverter4/IN: R9.1; also elsewhere on the board
/Inverter4/OUT: Q5.3 (D); also elsewhere on the board
/Inverter5/IN: R11.1; also elsewhere on the board
/Inverter5/OUT: Q6.3 (D); also elsewhere on the board
/Inverter6/IN: R13.1; also elsewhere on the board
/Inverter6/OUT: Q7.3 (D); also elsewhere on the board
/Inverter7/IN: R15.1; also elsewhere on the board
/Inverter7/OUT: Q8.3 (D); also elsewhere on the board
GND: Q2.2 (S), Q3.2 (S), Q4.2 (S), Q5.2 (S), Q6.2 (S), Q7.2 (S), Q8.2 (S), R4.2, R6.2, R8.2, R10.2, R12.2, R14.2, R16.2; also elsewhere on the board
unnamed: Q2.1 (G), R3.2, R4.1
unnamed: Q3.1 (G), R5.2, R6.1
unnamed: Q4.1 (G), R7.2, R8.1
unnamed: Q5.1 (G), R9.2, R10.1
unnamed: Q6.1 (G), R11.2, R12.1
unnamed: Q7.1 (G), R13.2, R14.1
unnamed: Q8.1 (G), R15.2, R16.1

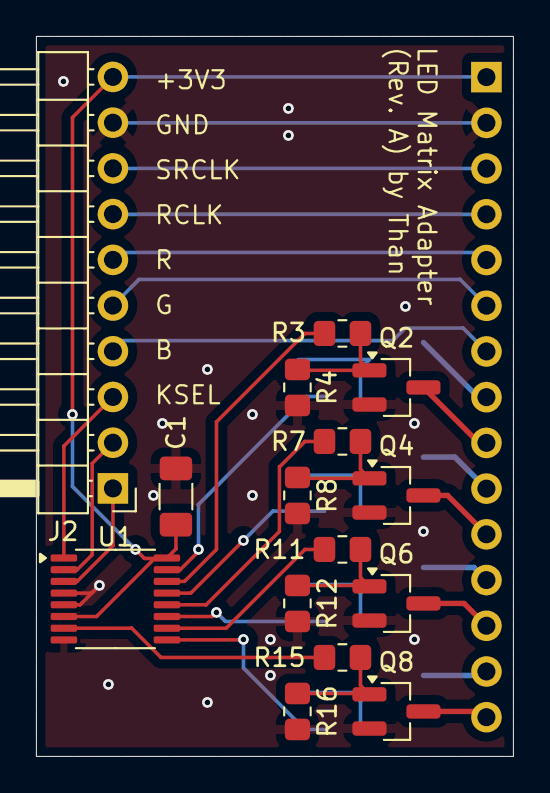
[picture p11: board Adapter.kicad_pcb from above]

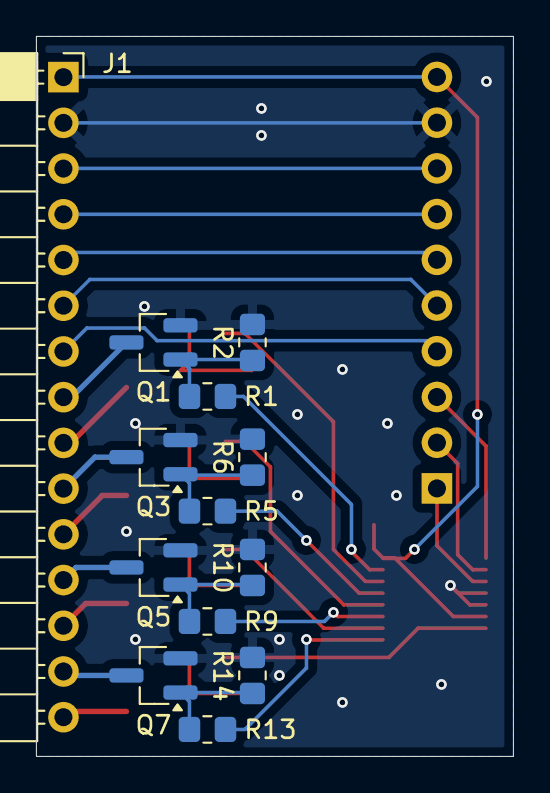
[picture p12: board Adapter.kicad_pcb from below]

Board: 2 copper layers, 26.5 x 40.0 mm, 28 parts (13 on the bottom side), 34 nets.

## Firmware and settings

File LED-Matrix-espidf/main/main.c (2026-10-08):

// Copyright (c) 2026 Boonyakorn Thanpanit
#include "driver/gptimer.h"
#include "freertos/FreeRTOS.h"
#include "freertos/task.h"
#include "matrix.h"

uint8_t matrix_buffer[MATRIX_HEIGHT][MATRIX_WIDTH][3] = {0};

#if USE_MATRIX_BITBANG
const gpio_num_t MATRIX_SER_PINS[SUBMATRIX_PER_COL][3] = {
    {MATRIX_SER_PIN_0_R, MATRIX_SER_PIN_0_G, MATRIX_SER_PIN_0_B}};  //,
// {MATRIX_SER_PIN_1_R, MATRIX_SER_PIN_1_G, MATRIX_SER_PIN_1_B},
// {MATRIX_SER_PIN_2_R, MATRIX_SER_PIN_2_G, MATRIX_SER_PIN_2_B},
// {MATRIX_SER_PIN_3_R, MATRIX_SER_PIN_3_G, MATRIX_SER_PIN_3_B},
// {MATRIX_SER_PIN_4_R, MATRIX_SER_PIN_4_G, MATRIX_SER_PIN_4_B}};

static bool RefreshMatrixTask(gptimer_handle_t timer,
                              const gptimer_alarm_event_data_t* edata,
                              void* user_ctx) {
  MatrixDraw((const uint8_t***)matrix_buffer);
  return false;
}
#endif  // USE_MATRIX_BITBANG

void app_main() {
  MatrixInit();

#if USE_MATRIX_BITBANG
  // Create a timer to refresh the matrix at regular intervals
  gptimer_handle_t gptimer;
  gptimer_config_t timer_config = {
      .clk_src = GPTIMER_CLK_SRC_DEFAULT,
      .direction = GPTIMER_COUNT_UP,
      .resolution_hz = 1000000,  // 1 MHz resolution
  };
  ESP_ERROR_CHECK(gptimer_new_timer(&timer_config, &gptimer));

  // Configure the timer to trigger an alarm every 100 microseconds
  gptimer_alarm_config_t alarm_config = {
      .alarm_count = 100,  // Trigger every 100 microseconds
      .reload_count = 0,
      .flags.auto_reload_on_alarm = true,
  };
  ESP_ERROR_CHECK(gptimer_set_alarm_action(gptimer, &alarm_config));

  // Configure the callback for the timer alarm
  gptimer_event_callbacks_t cbs = {
      .on_alarm = RefreshMatrixTask,
  };
  ESP_ERROR_CHECK(gptimer_register_event_callbacks(gptimer, &cbs, NULL));
  ESP_ERROR_CHECK(gptimer_enable(gptimer));  // Enable the timer
  ESP_ERROR_CHECK(gptimer_start(gptimer));   // Start the timer
#endif                                       // USE_MATRIX_BITBANG

  for (int row = 0; row < MATRIX_HEIGHT; row++) {
    for (int col = 0; col < MATRIX_WIDTH; col++) {
      matrix_buffer[row][col][0] = (row + col) % 256;  // Red
      matrix_buffer[row][col][1] = (row * 2) % 256;    // Green
      matrix_buffer[row][col][2] = (col * 3) % 256;    // Blue
    }
  }

  while (1) {
    vTaskDelay(pdMS_TO_TICKS(1000));
  }
  // xTaskCreate(RefreshMatrixTask, "RefreshMatrixTask", 4096, NULL, 10, NULL);
}

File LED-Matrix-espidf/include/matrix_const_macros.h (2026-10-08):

// Copyright (c) 2026 Boonyakorn Thanpanit
#pragma once

#define MATRIX_WIDTH 8
#define MATRIX_HEIGHT 8

#if USE_MATRIX_BITBANG
/*
 * Matrix dimensions
 *
 * One submatrix is defined as 8x8 LEDs. The total matrix size must be a
 * multiple of 8 in both dimensions.
 */
#define SUBMATRIX_PER_ROW (MATRIX_WIDTH >> 3)
#define SUBMATRIX_PER_COL (MATRIX_HEIGHT >> 3)

// Pin definitions (may change later)
#define DEMUX_A0_PIN 0
#if !USE_MATRIX_ASM
#define DEMUX_A1_PIN (DEMUX_A0_PIN + 1)
#define DEMUX_A2_PIN (DEMUX_A0_PIN + 2)
#endif  // !USE_MATRIX_ASM

#define DEMUX_BIT_MASK (~(7 << DEMUX_A0_PIN))
#define SRCLK_PIN 22
#define RCLK_PIN 23

#define MATRIX_SER_PIN_0_R 3
#define MATRIX_SER_PIN_0_G 4
#define MATRIX_SER_PIN_0_B 5
#define MATRIX_SER_PIN_1_R 6
#define MATRIX_SER_PIN_1_G 7
#define MATRIX_SER_PIN_1_B 8
#define MATRIX_SER_PIN_2_R 9
#define MATRIX_SER_PIN_2_G 10
#define MATRIX_SER_PIN_2_B 11
#define MATRIX_SER_PIN_3_R 12
#define MATRIX_SER_PIN_3_G 13
#define MATRIX_SER_PIN_3_B 15
#define MATRIX_SER_PIN_4_R 18
#define MATRIX_SER_PIN_4_G 19
#define MATRIX_SER_PIN_4_B 20
#else

#endif  // USE_MATRIX_BITBANG

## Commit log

2025-12-26 Initial PCB commit
    [Adapter.kicad_pcb, Adapter.kicad_sch, Inverter.kicad_sch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]
2025-12-26 export step file for adapter pcb
    [Adapter.kicad_pcb, Adapter.step]
2025-12-26 export carrier pcb step model
    [LED matrix.kicad_pcb, LED matrix.kicad_sch, matrix.kicad_sch]
2025-12-26 export matrix module step model
    [LED matrix.kicad_pcb]
2026-01-01 fix wrong footprint/symbol
    [LED matrix.kicad_pcb, LED matrix.kicad_sch]
2026-01-07 move matrix serial pin definitions
2026-01-17 refactor serial pin defns
2026-07-30 Create display driver FPGA project
2026-07-30 Generate SPI IP core
2026-08-04 Remove SPI IP core
2026-10-07 Define SPI commands
2026-10-11 Change FPGA Pin mapping
2026-10-11 Done (?) with PCB
2026-11-05 Configure driver dev process
    Configure driver development process:
    - pin constraints
    - clock constraints
    - download process
2026-11-05 Update .gitignore for PCB exports
